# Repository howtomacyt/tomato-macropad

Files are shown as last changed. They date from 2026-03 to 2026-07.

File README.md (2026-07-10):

# tomato-macropad
This is my macropad that I somehow spent nearly 4 straight days designing!!!  
Felt very torturous at times but I am glad it's over and I've got something to show for all that work (hopefully)

## Features ##
9 customisable keys, 1 rotary encoder, 1 OLED Screen. 
Connect via USB-C. 

## CAD Model ##
Everything fits together using 4 M3 Bolts and heatset inserts. 4 for the case and PCB. 
It has 2 separate printed pieces.


**V2:**


## PCB ##
Experimented with RGB lights, but decided not to include them due to the added complexity in tracing. I also had difficulties implementing the firmware for it. 
I may consider switching to KMK. 



## Firmware ##
This hackpad uses QMK firmware. The keys are customisable. 

## Bill of Materials ##

- 9x Cherry MX Switches
- 9x DSA Keycaps
- 4x M3x5x4 Heatset inserts
- 4x M3x16mm SHCS Bolts
- 9x 1N4148 DO-35 Diodes
- 1x 0.91" 128x32 OLED Display
- 1x EC11 Rotary Encoder
- 1x XIAO RP2040



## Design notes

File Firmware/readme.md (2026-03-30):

# tomato_macropad

tomato_macropad

*A short description of the keyboard/project*

* Keyboard Maintainer: [tomato](https://github.com/taiyotomatoe)
* Hardware Supported: *The PCBs, controllers supported*
* Hardware Availability: *Links to where you can find this hardware*

Make example for this keyboard (after setting up your build environment):

    make tomato_macropad:default

Flashing example for this keyboard:

    make tomato_macropad:default:flash

See the [build environment setup](https://docs.qmk.fm/#/getting_started_build_tools) and the [make instructions](https://docs.qmk.fm/#/getting_started_make_guide) for more information. Brand new to QMK? Start with our [Complete Newbs Guide](https://docs.qmk.fm/#/newbs).

## Bootloader

Enter the bootloader in 3 ways:

* **Bootmagic reset**: Hold down the key at (0,0) in the matrix (usually the top left key or Escape) and plug in the keyboard
* **Physical reset button**: Briefly press the button on the back of the PCB - some may have pads you must short instead
* **Keycode in layout**: Press the key mapped to `QK_BOOT` if it is available

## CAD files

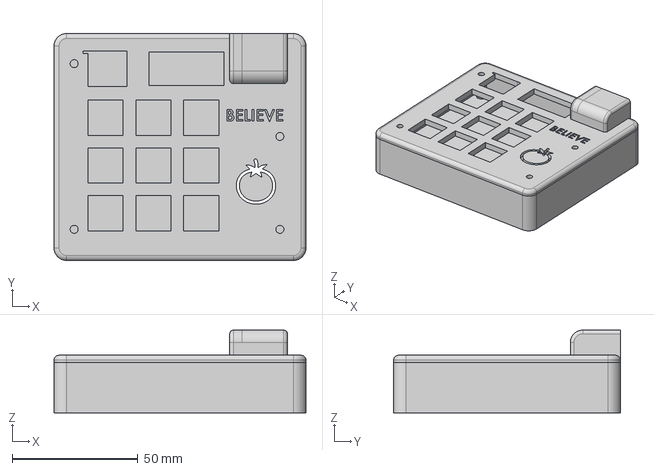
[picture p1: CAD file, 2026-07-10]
CAD/Full Assembly.step
100.4 x 90.4 x 33.0 mm
Bottom x 2
Top

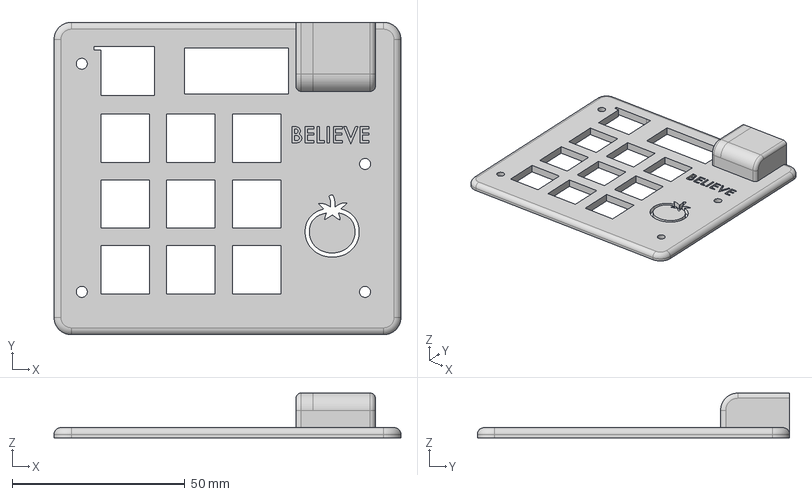
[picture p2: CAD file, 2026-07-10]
CAD/Top.step
100.4 x 90.4 x 13.0 mm

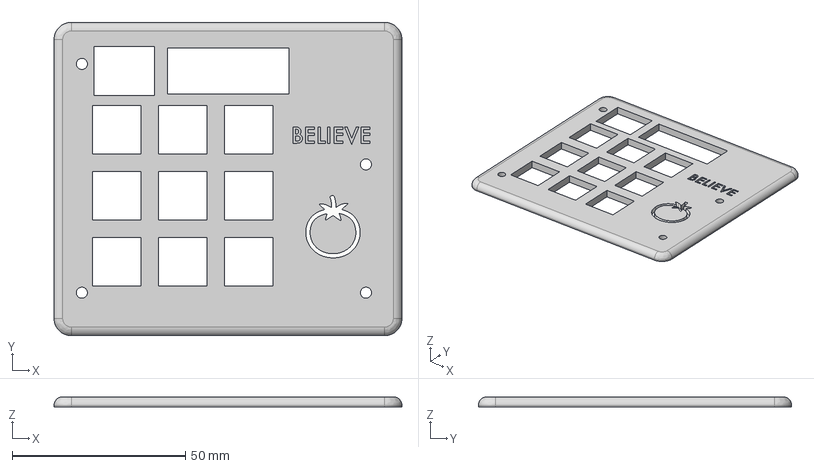
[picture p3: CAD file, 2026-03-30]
production/Top.step
100.4 x 90.4 x 3.00 mm

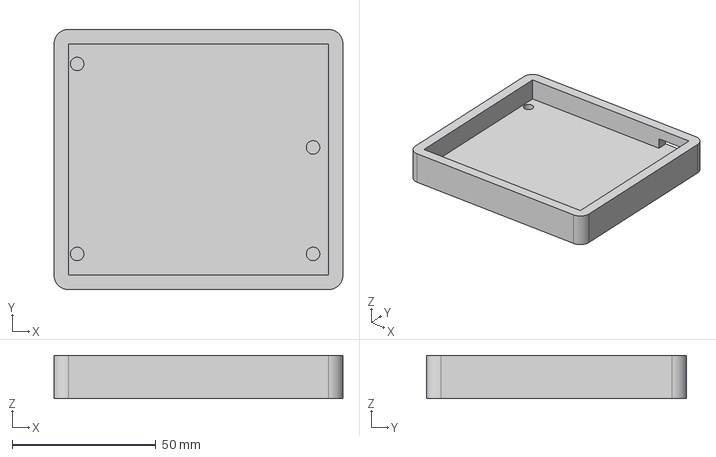
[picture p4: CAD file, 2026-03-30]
production/Bottom.step
100.4 x 90.4 x 15.0 mm

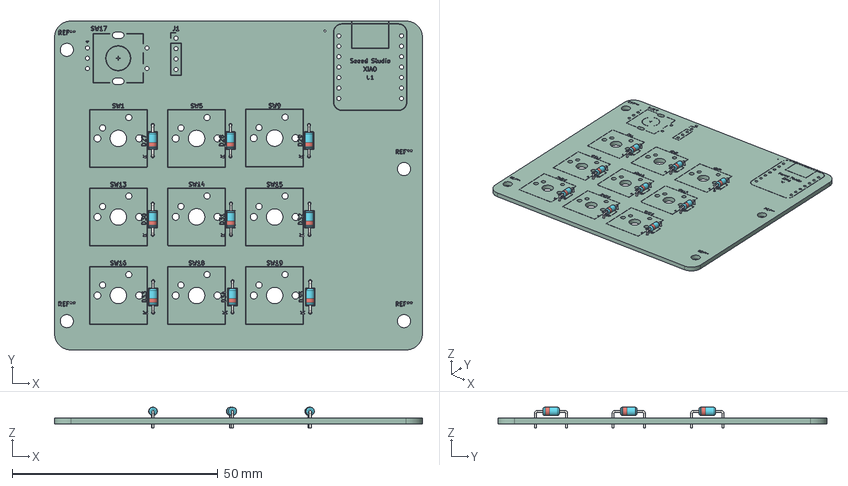
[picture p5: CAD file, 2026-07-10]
CAD/pcb.step
89.5 x 80.0 x 5.01 mm
D_DO-35_SOD27_P7.62mm_Horizontal x 9
macropad_silkscreen
macropad_PCB

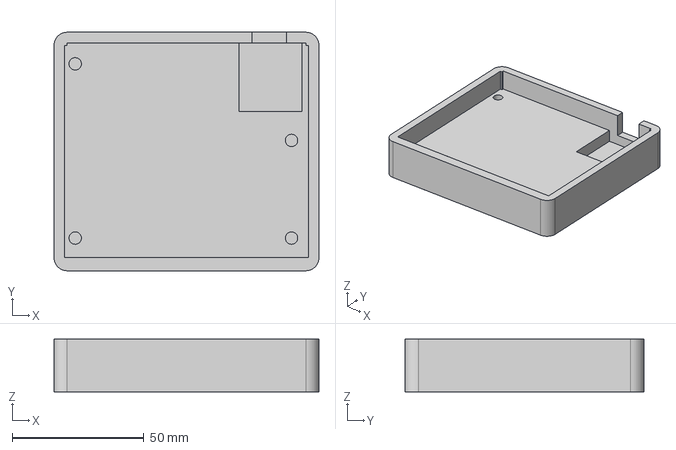
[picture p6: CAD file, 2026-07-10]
CAD/Bottom.step
100.4 x 90.4 x 20.0 mm

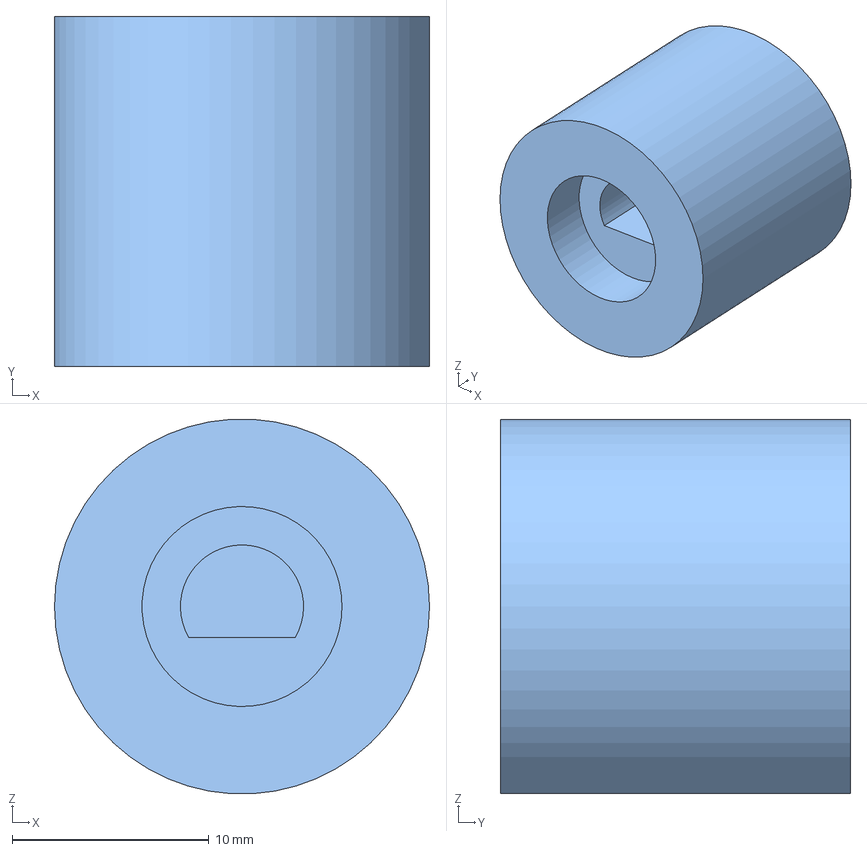
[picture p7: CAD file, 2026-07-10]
CAD/Knob.step
19.1 x 17.8 x 19.0 mm

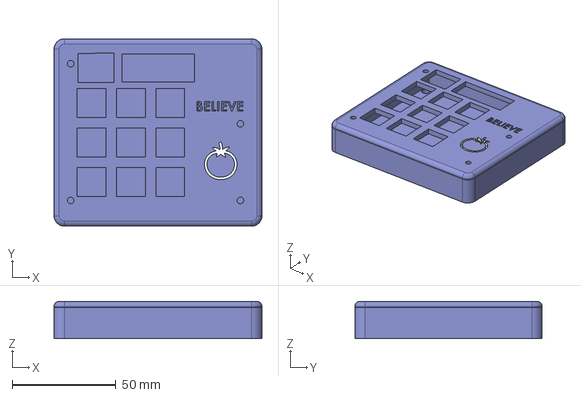
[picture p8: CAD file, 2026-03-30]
CAD/final case design v9.step
100.4 x 90.4 x 18.0 mm
Top
Bottom

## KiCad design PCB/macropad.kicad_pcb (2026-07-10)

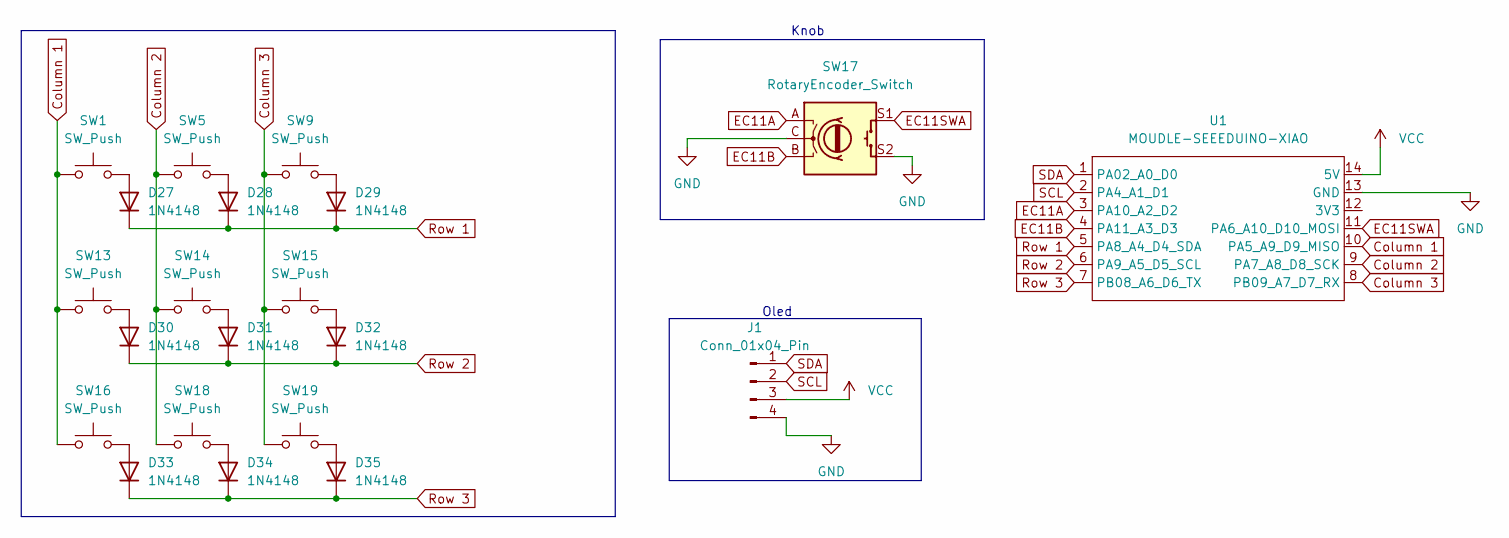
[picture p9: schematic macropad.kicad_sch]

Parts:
D27, D28, D29, D30, D31, D32, D33, D34, D35: 1N4148; D_DO-35_SOD27_P7.62mm_Horizontal
J1: Conn_01x04_Pin; PinHeader_1x04_P2.54mm_Vertical
SW1, SW5, SW9, SW13, SW14, SW15, SW16, SW18, SW19: SW_Push; SW_Cherry_MX_1.00u_PCB
SW17: RotaryEncoder_Switch; RotaryEncoder_Alps_EC11E-Switch_Vertical_H20mm
U1: MOUDLE-SEEEDUINO-XIAO; XIAO-Generic-Hybrid-14P-2.54-21X17.8MM

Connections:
Column 1: SW1.1, SW13.1, SW16.1, U1.10 (PA5_A9_D9_MISO)
Column 2: SW5.1, SW14.1, SW18.1, U1.9 (PA7_A8_D8_SCK)
Column 3: SW9.1, SW15.1, SW19.1, U1.8 (PB09_A7_D7_RX)
EC11A: SW17.A, U1.3 (PA10_A2_D2)
EC11B: SW17.B, U1.4 (PA11_A3_D3)
EC11SWA: SW17.S1, U1.11 (PA6_A10_D10_MOSI)
GND: J1.4, SW17.C, SW17.S2, U1.13 (GND)
unnamed: D27.2 (A), SW1.2
unnamed: D28.2 (A), SW5.2
unnamed: D29.2 (A), SW9.2
unnamed: D30.2 (A), SW13.2
unnamed: D31.2 (A), SW14.2
unnamed: D32.2 (A), SW15.2
unnamed: D33.2 (A), SW16.2
unnamed: D34.2 (A), SW18.2
unnamed: D35.2 (A), SW19.2
Row 1: D27.1 (K), D28.1 (K), D29.1 (K), U1.5 (PA8_A4_D4_SDA)
Row 2: D30.1 (K), D31.1 (K), D32.1 (K), U1.6 (PA9_A5_D5_SCL)
Row 3: D33.1 (K), D34.1 (K), D35.1 (K), U1.7 (PB08_A6_D6_TX)
SCL: J1.2, U1.2 (PA4_A1_D1)
SDA: J1.1, U1.1 (PA02_A0_D0)
VCC: J1.3, U1.14 (5V)

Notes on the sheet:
Oled
Knob

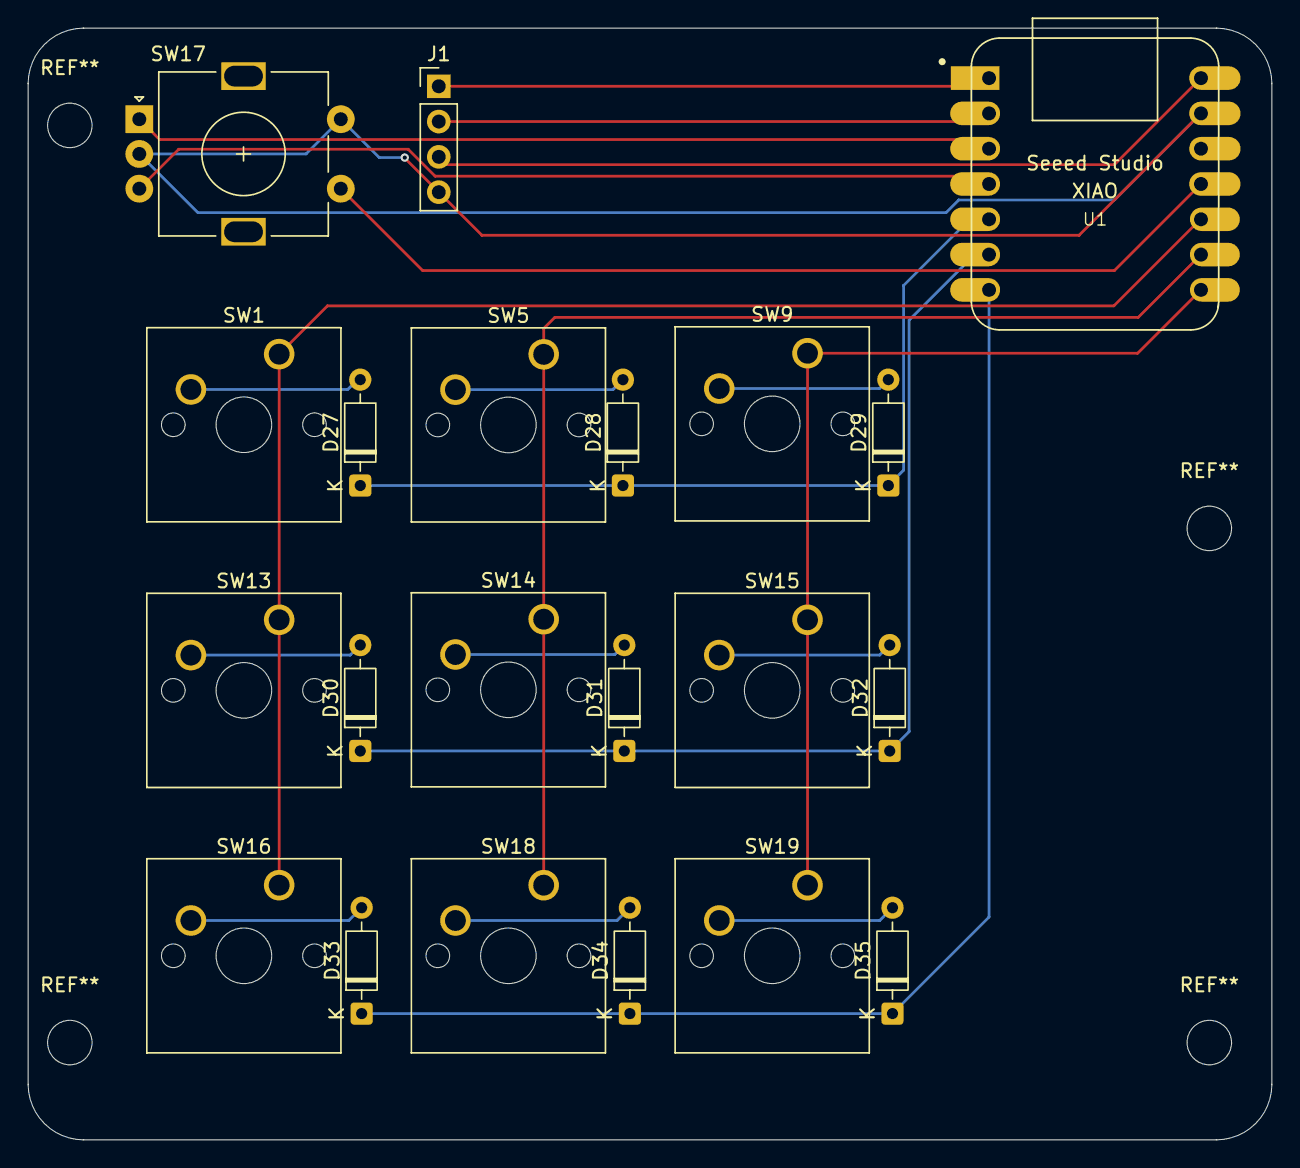
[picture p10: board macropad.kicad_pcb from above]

Board: 2 copper layers, 89.5 x 80.0 mm, 21 parts (0 on the bottom side), 22 nets.

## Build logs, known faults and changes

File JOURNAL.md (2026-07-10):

# Log
**I didn't journal the design process when I made this macropad as part of Blueprint. 
I now have the PCB and the hackpad kit arrived, so I am finishing the build.**
### Total Hours (For Building) - 9
### Time spent on design - approx. 14

## 9 July
I just got the PCB - was not expecting this, as the JLCPCB website was not very helpful with tracking. 

I started by testing the hackpad enclosure - turns out I didn't make the bottom thick enough, because the heat-set insert made a hole through the bottom of the plastic. 
Speaking of which they're pretty satisfying to push in. 

The bottom of the PCB has pins sticking out of it (such as from the MCU). Therefore, I had to make some holes to account for this, so the pcb could lie flat. (Before and after)

I also made some changes to the usb-c port to adjust for its position, as it wasn't lined up: 


I started soldering the switches/diodes on. I think I may have ingested some fumes, but soldering is pretty satisfying! This took quite a bit of time - I didn't want to make any mistakes and ruin parts, as it was my first time. 


### Hours: 3

## 10 July 
Spent **4 hours today testing the macropad**. I didn't want to waste all of my switches before I was sure that it'd work, as de-soldering them would be a challenge to say the least (I just learnt how to solder..). 

I was sorta having a breakdown as none of the key presses were being detected, and I tried with multiple languages... 

Somehow the problem was just because I had misunderstood the pinout, becauase there are multiple of them??? Previous me didn't realise that which caused me lots of unnecessary pain. 


I also had difficulties connecting to the RP2040, because connecting my cable to one port on my computer wouldn't yield the same result as another port, or at least that's what I remember. 

I tried restarting my computer, to see if that would make it detect the rp2040's disk. I finally found a fix (pressing the tiny Bootloader button then releasing it once the cable was plugged in) but it took me a while. 

I thorugh it looked too bare-bones, which is when I realised I didn't have a knob for the encoder (that's why...) 

So I made one real quick. 

I'm now finally done assembling and uploading the firmware - the macropad is fully functional!!! 


### Hours: 6

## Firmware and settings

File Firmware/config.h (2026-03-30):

#define ENCODER_A_PINS {GP3}
#define ENCODER_B_PINS {GP4}
#define ENCODER_RESOLUTION 4

#define I2C_DRIVER I2CD1
#define I2C1_SDA_PIN GP1
#define I2C1_SCL_PIN GP2

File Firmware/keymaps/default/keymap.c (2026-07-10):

// Copyright 2023 QMK
// SPDX-License-Identifier: GPL-2.0-or-later

#include QMK_KEYBOARD_H

enum layer_names {
    _MAC_DEFAULT, 
    _NUM_PAD
};

const uint16_t PROGMEM keymaps[][MATRIX_ROWS][MATRIX_COLS] = {
    [0] = LAYOUT_ortho_3x3(
        KC_MUTE,   KC_VOLD,   KC_VOLU,  
        KC_BRID,   KC_BRIU,   KC_MCTL, 
        KC_PGDN,   KC_PGUP,   KC_DEL
    // ), 
    // To be configured later
    // [1] = LAYOUT_ortho_3x3(
    //     KC_1,   KC_2,   KC_3,  
    //     KC_4,   KC_5,   KC_6, 
    //     KC_7,   KC_8,   KC_9
     )
};


#ifdef ENCODER_MAP_ENABLE
const uint16_t PROGMEM encoder_map[][NUM_ENCODERS][NUM_DIRECTIONS] = {
    [0] = { ENCODER_CCW_CW(KC_VOLU, KC_VOLD) },
    [1] = { ENCODER_CCW_CW(KC_VOLU, KC_VOLD) }
};
#endif

// //code for layer switching TBI

#ifdef OLED_ENABLE
bool oled_task_user() {
    oled_set_cursor(0,1);
    switch (get_highest_layer(layer_state)) {
        case _MAC_DEFAULT: 
        oled_write("hope you have a nice day.", false);
        break; 

        case _NUM_PAD: 
        oled_write("Number Pad", false);
    }
    return false; 
};

#endif

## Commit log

2026-03-30 finally done
    [Bottom.step, Top.step, macropad.kicad_pcb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]
2026-03-30 cad files
    [final case design v8.step]
2026-03-30 cad file revised
    [Top.step, final case design v8.step, final case design v9.step]
